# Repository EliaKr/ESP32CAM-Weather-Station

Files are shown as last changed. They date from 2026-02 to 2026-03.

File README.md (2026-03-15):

# ESP32CAM-Weather-Station

## Electronics

This project uses a custom weather-station PCB that combines **power management**, **protection**, and an **I2C sensor/expansion bus**.

### Power features
- Supports **battery input** with input protection.
- Supports **solar input** with surge/transient protection.
- Includes **battery charging** (status indicators and a battery temperature/thermistor input).
- Provides regulated rails for the rest of the system (including a **3.3V rail** for sensors/logic).
- Breakouts/headers for accessing power rails (battery and regulated output) for debugging or external loads.

### Measurement & sensing features
- On-board sensing for **battery voltage** and **solar/charging voltage**.
- On-board environmental sensing (temperature/humidity/pressure/gas resistance).
- On-board gas sensing (VOC/NOx measurements).
- On-board ambient light sensing (lux).
- ESP32-CAM on-board sky camera.

### I2C bus + expansion features
- I2C bus includes **pullups** and **ESD/transient protection**.
- Multiple **external I2C expansion headers** (3.3V / GND / SDA / SCL) for additional sensors.

### Extras
- A PCB that makes the board compatible with the Raspberry Pi Pico (Original or W or 2 or 2W) is also included in the design files.

### Media (photos and design files)

> Photos below are from **testing / bring-up** and may show temporary wiring or rework.

**PCB front (testing photo)**  
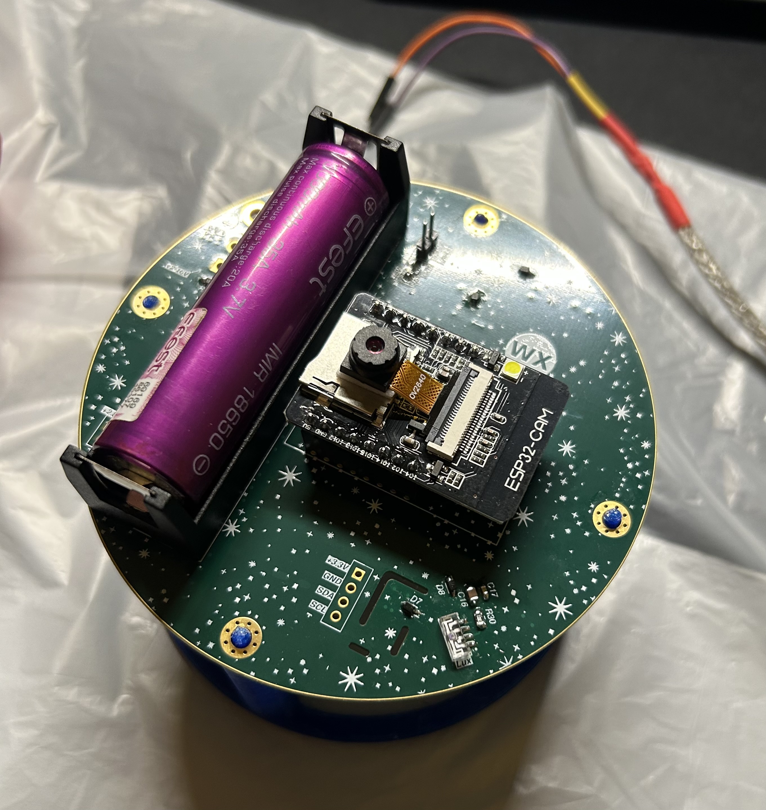
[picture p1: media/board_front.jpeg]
PCB front during testing


**PCB back (testing photo)**  
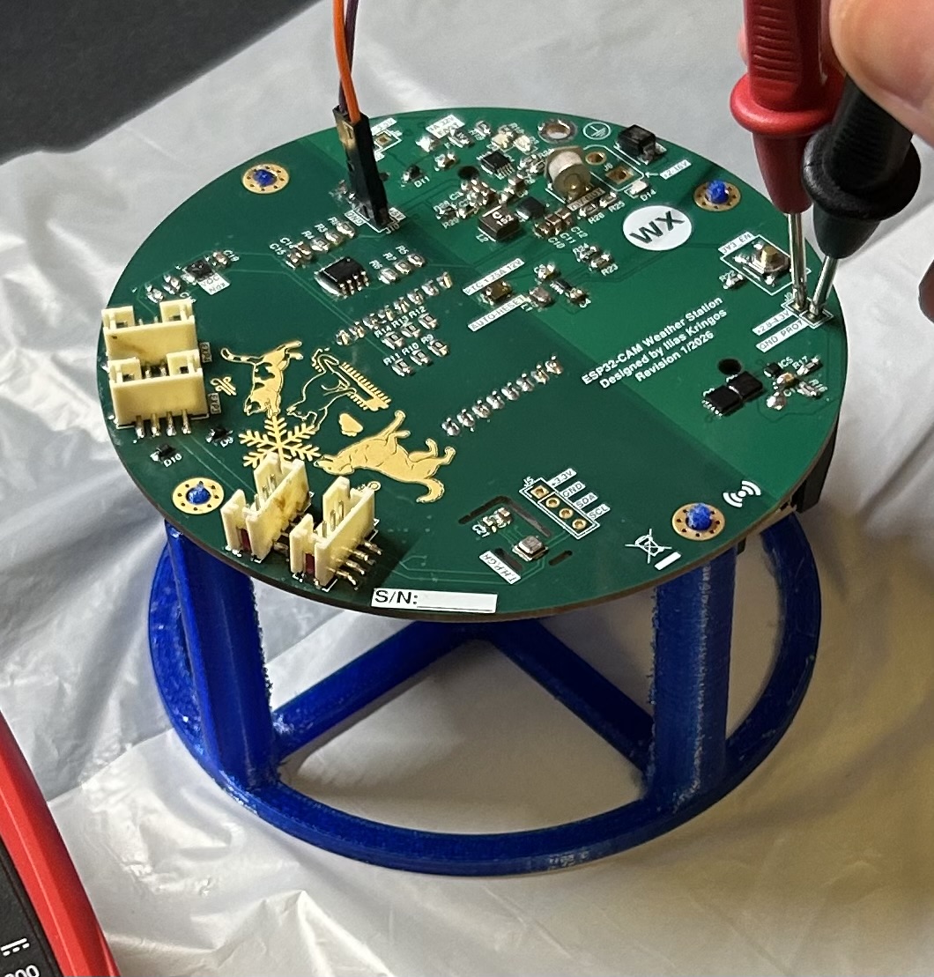
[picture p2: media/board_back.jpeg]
PCB back during testing


**KiCad PCB layout (screenshot)**  
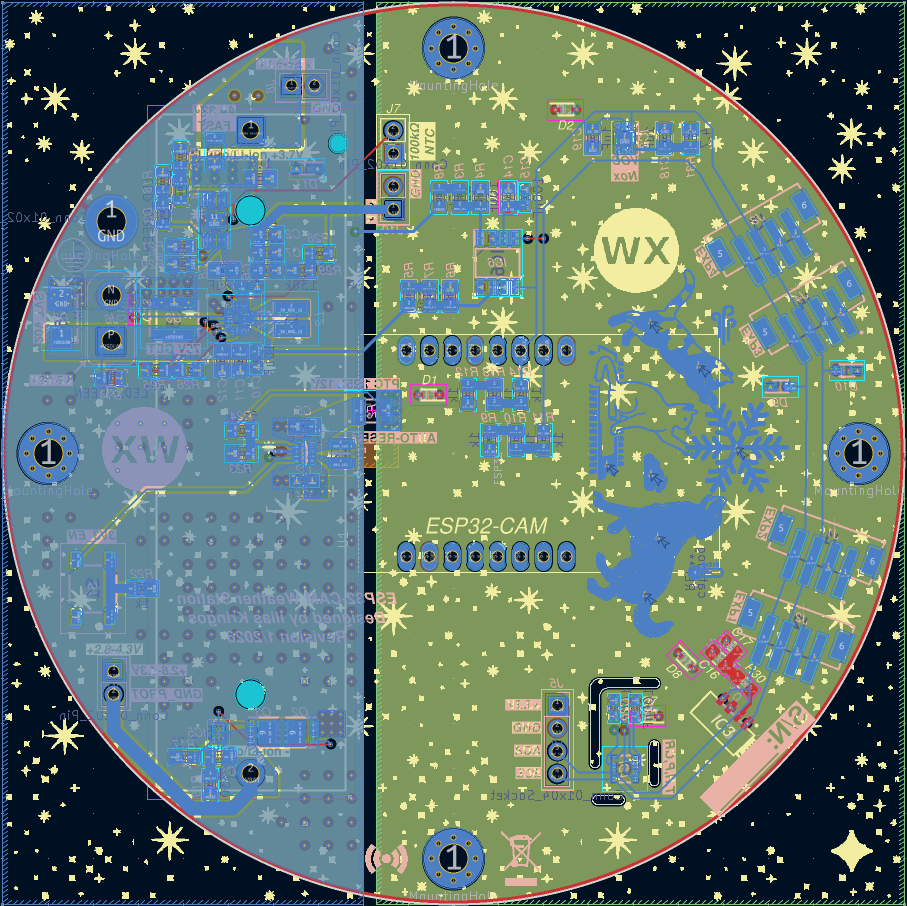
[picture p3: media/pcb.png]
KiCad PCB layout


**Schematic (export image)**  
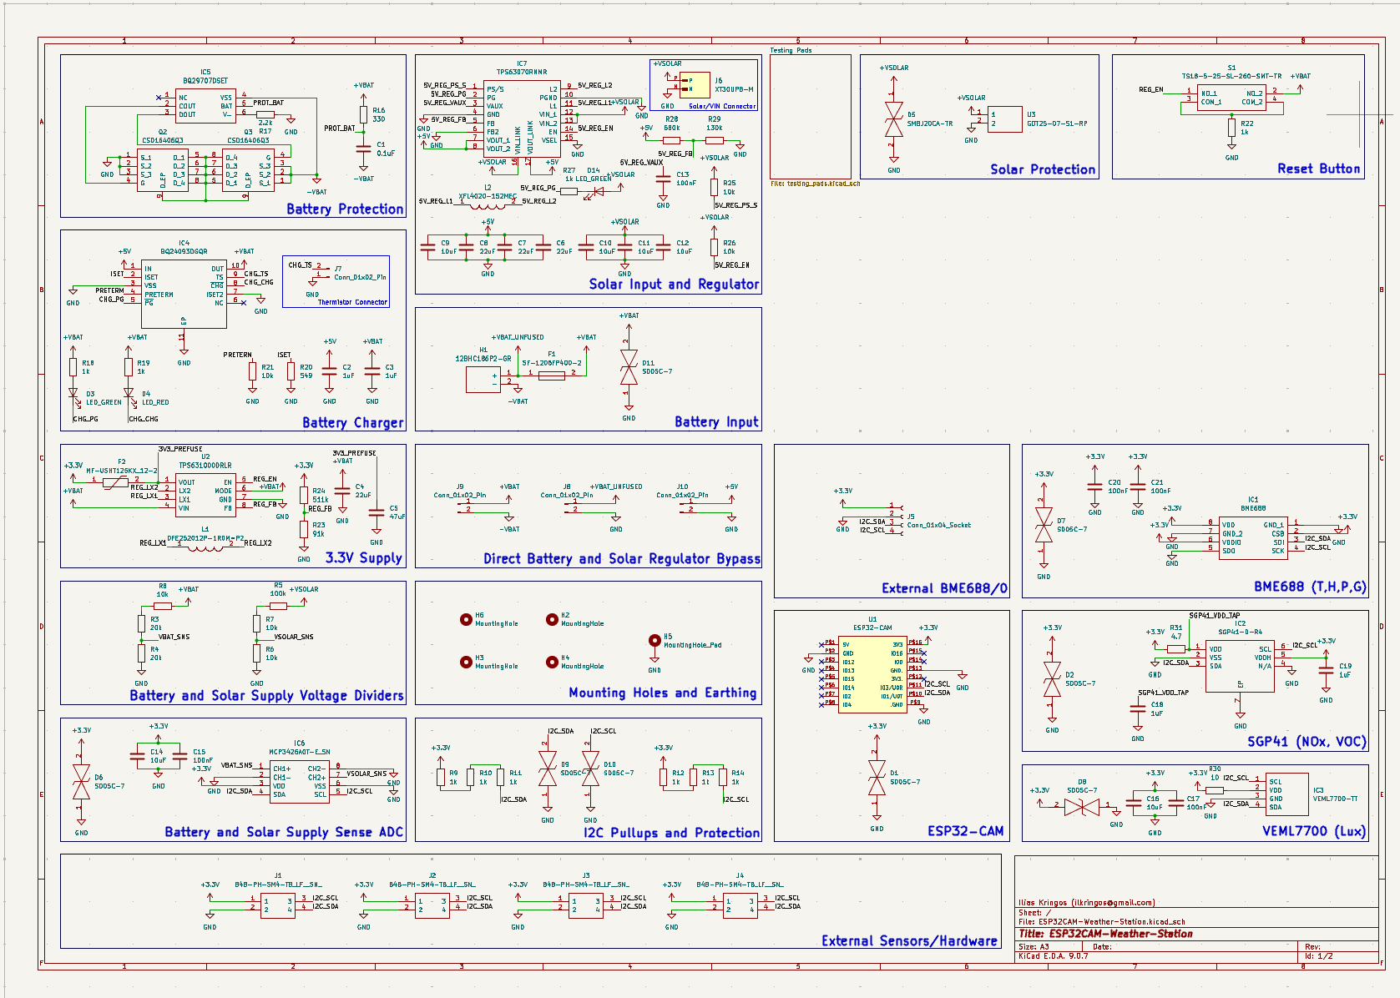
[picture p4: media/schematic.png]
Schematic


---

## Mechanical design (placeholder)

- TODO: enclosure details, mounting, weatherproofing, cable glands, venting strategy, sensor placement.
- TODO: 3D print files / CAD links, tolerances, and assembly steps.
- TODO: photos/diagrams.

---

## Software: Pico Weather Station (Client) + Local Ingest Server (HTTP + HMAC)

This project consists of:

- **Client (Raspberry Pi Pico 2 W)**: reads sensors over I2C and periodically posts measurements to a server.
- **Server (Python)**: accepts measurements over **HTTP** and protects the endpoint with:
  - Bearer token allow-list (multiple devices supported)
  - HMAC-SHA256 request signature (fast reject of unauthenticated spam)
  - Rate limiting (per IP and per token)
  - Max body size and max concurrency
  - CSV logging to two files (same schema)

> Security note: This design does **not** encrypt the data in transit (it is HTTP). It **does** prevent unauthorized clients from successfully sending data (and helps prevent trivial overload). If you need confidentiality, use HTTPS.

### Repository layout (recommended)

#### PlatformIO (client)
- `src/measurement_post_requests.cpp` (or `src/main.cpp`) — client code
- `include/client_config.h` — user-created (not committed)
- `include/wificredentials.h` — user-created (not committed)

#### Server (Python)
- `server/server_config.py`
- `server/server_http_hmac.py`

---

### 1) Server setup (Python)

#### 1.1 Requirements
- Python 3.9+ recommended (stdlib only)

No pip packages required.

#### 1.2 Files
Create a directory (example):
```
server/
  server_http_hmac.py
  server_config.py
```

#### 1.3 Configure `server_config.py`
Key options:
- Bind / endpoint: `HOST`, `PORT`, `INGEST_PATH`
- Auth: `AUTH_TOKENS`, `ALLOW_BEARER_HEADER`
- Protections: `REQUIRE_HMAC`, `REQUIRE_TIMESTAMP`, `RATE_LIMIT_*`, `MAX_BODY_BYTES`, `MAX_CONCURRENT_REQUESTS`
- CSV: `CSV_PATH_1`, `CSV_PATH_2`, `CSV_HEADER`

> If you are not setting time on the Pico (no NTP), set `REQUIRE_TIMESTAMP = False`.

#### 1.4 Run the server
From the `server/` directory:
```bash
python3 server_http_hmac.py
```

#### 1.5 Test health endpoint
```bash
curl http://<server-ip>:<port>/health
```

---

### 2) Client setup (PlatformIO / Pico 2 W)

#### 2.1 Create user config headers (required)
Create these two files under the PlatformIO include directory:
- `include/client_config.h`
- `include/wificredentials.h`

These should not be committed (they contain secrets).

##### `include/wificredentials.h`
```cpp
#pragma once

#define WIFI_SSID "YOUR_WIFI_SSID"
#define WIFI_PASS "YOUR_WIFI_PASSWORD"

#define USE_STATIC_IP 1

#if USE_STATIC_IP
  #define WIFI_LOCAL_IP   IPAddress(192,168,2,55)
  #define WIFI_DNS_IP     IPAddress(1,1,1,1)
  #define WIFI_GATEWAY_IP IPAddress(192,168,2,1)
  #define WIFI_SUBNET_IP  IPAddress(255,255,255,0)
#endif
```

##### `include/client_config.h`
```cpp
#pragma once

#define DEVICE_ID "pico2w-01"
#define SERVER_URL "http://192.168.2.8:8080/ingest"

// Token secret: must exist in server_config.AUTH_TOKENS
#define AUTH_TOKEN "CHANGE_ME_TO_A_LONG_RANDOM_SECRET"

#define POST_INTERVAL_MS 1000
#define HTTP_TIMEOUT_MS 5000
```

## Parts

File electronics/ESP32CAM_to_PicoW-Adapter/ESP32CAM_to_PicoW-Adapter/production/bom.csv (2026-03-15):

Designator | Footprint | Quantity | Value | LCSC Part #
A1 | RaspberryPi_Pico_Common_THT | 1 | RaspberryPi_Pico_W
D1 | D_DO-41_SOD81_P10.16mm_Horizontal | 1 | 1N5818
U1 | ESP32-CAM | 1 | ESP32-CAM

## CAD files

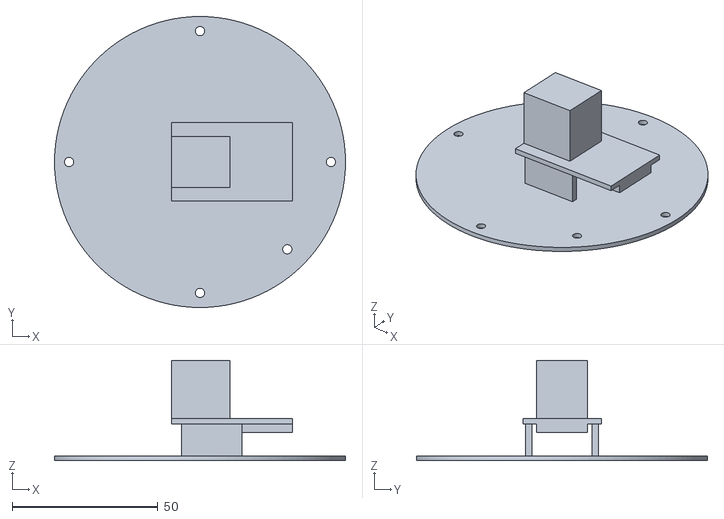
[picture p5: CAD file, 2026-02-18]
mechanical/Board.stl
100.0 x 100.0 x 34.4

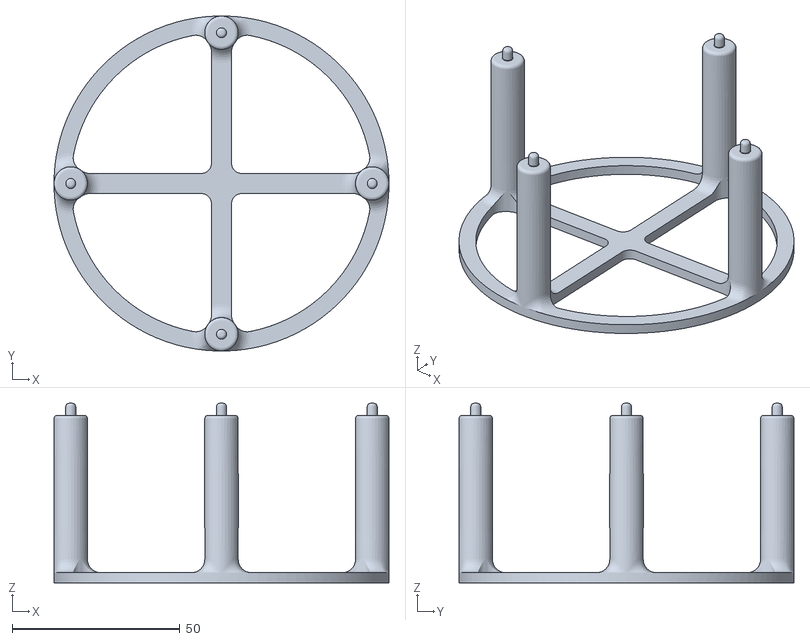
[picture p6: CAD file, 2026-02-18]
mechanical/Soldering+Base.stl
100.0 x 100.0 x 53.6

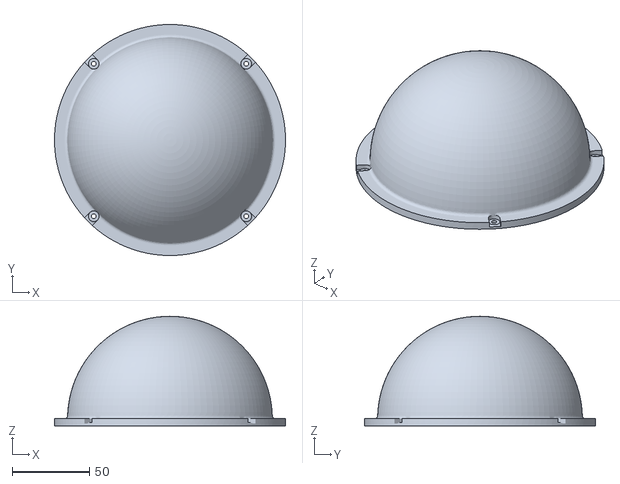
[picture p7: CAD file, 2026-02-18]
mechanical/Lid.stl
150.0 x 150.0 x 71.1

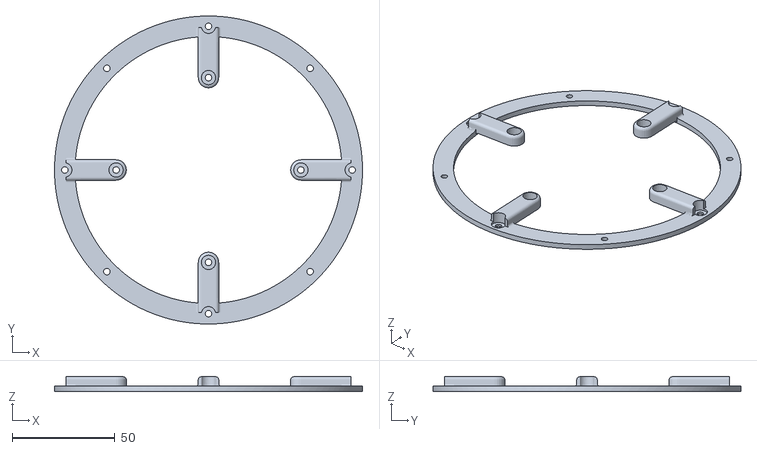
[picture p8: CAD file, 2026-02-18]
mechanical/Mount.stl
150.0 x 150.0 x 7.10

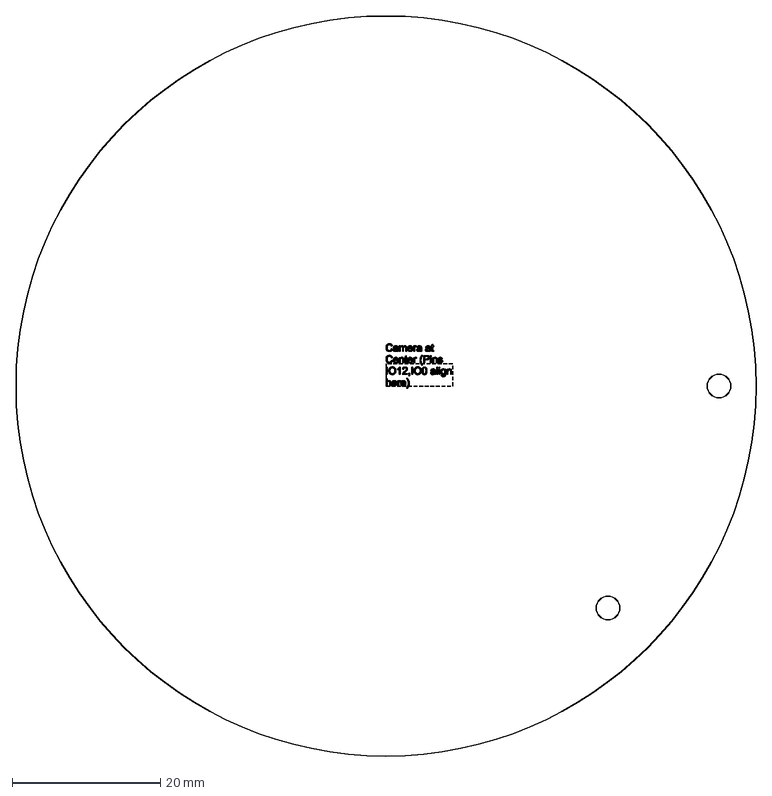
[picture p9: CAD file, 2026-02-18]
mechanical/Board Shape.dxf
100.0 x 100.0 mm

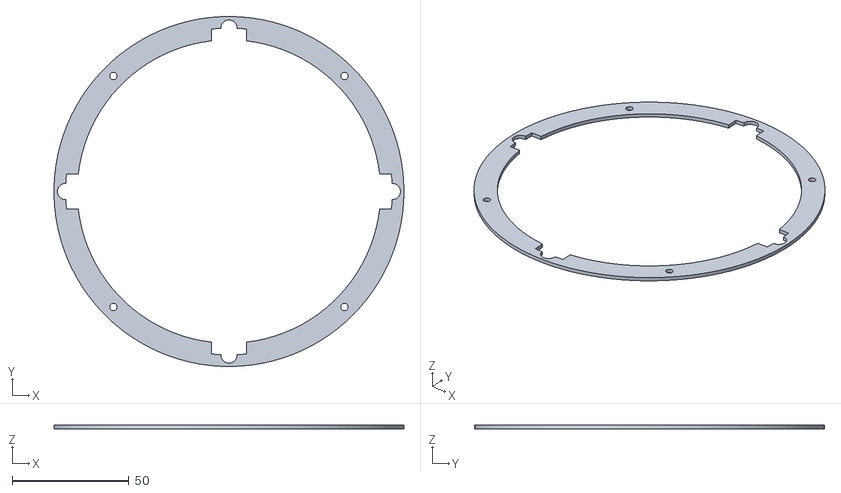
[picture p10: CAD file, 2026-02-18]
mechanical/Gasket.stl
150.0 x 150.0 x 1.60

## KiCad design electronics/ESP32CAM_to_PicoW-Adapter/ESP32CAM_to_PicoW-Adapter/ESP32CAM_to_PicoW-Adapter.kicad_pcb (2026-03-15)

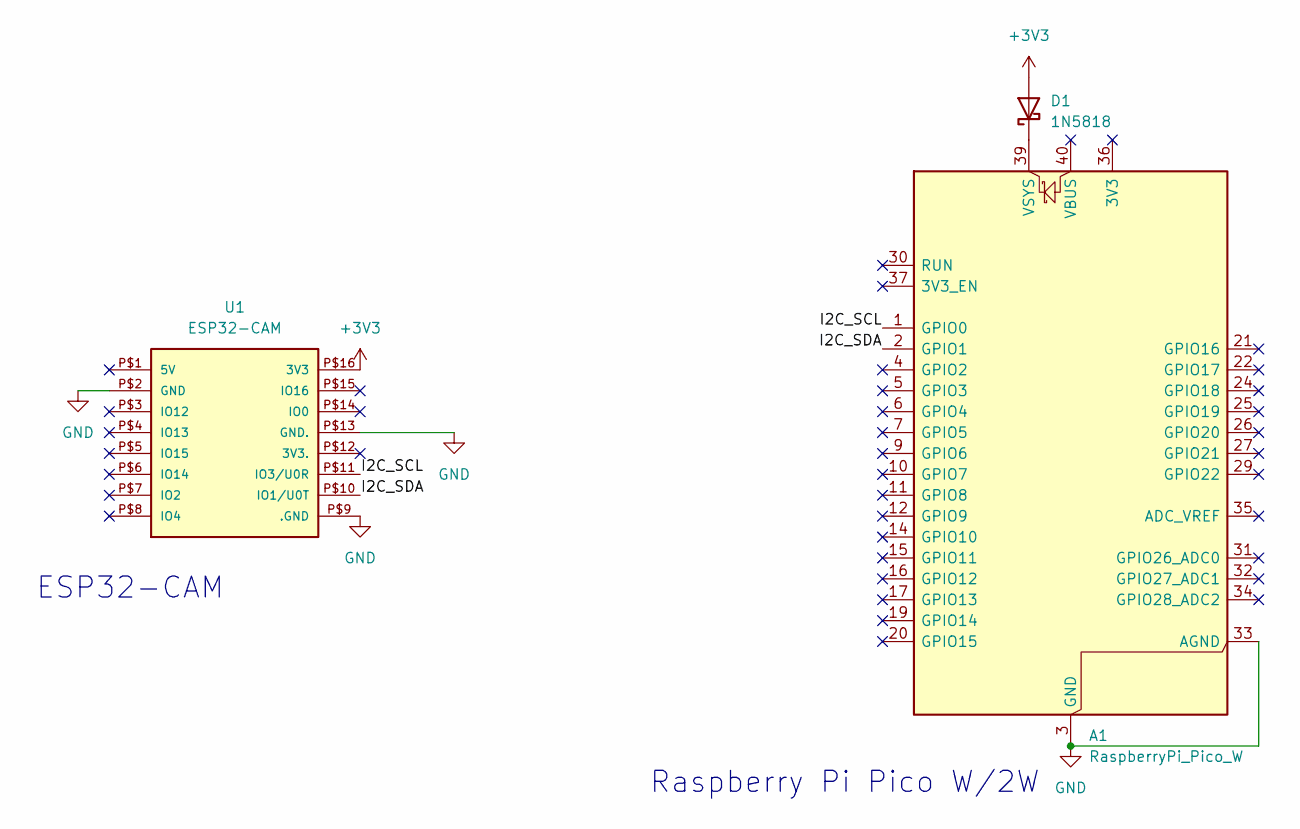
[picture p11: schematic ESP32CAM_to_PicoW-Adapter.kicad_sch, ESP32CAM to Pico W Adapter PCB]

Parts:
A1: RaspberryPi_Pico_W; RaspberryPi_Pico_Common_THT
D1: 1N5818; D_DO-41_SOD81_P10.16mm_Horizontal
U1: ESP32-CAM

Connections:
+3V3: D1.2 (A), U1.P$16 (3V3)
/I2C_SCL: A1.1 (GPIO0), U1.P$11 (IO3/U0R)
/I2C_SDA: A1.2 (GPIO1), U1.P$10 (IO1/U0T)
GND: A1.3 (GND), A1.8 (GND), A1.13 (GND), A1.18 (GND), A1.23 (GND), A1.28 (GND), A1.33 (AGND), A1.38 (GND), U1.P$2 (GND), U1.P$9 (.GND), U1.P$13 (GND.)
unnamed: A1.39 (VSYS), D1.1 (K)

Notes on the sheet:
ESP32-CAM
Raspberry Pi Pico W/2W

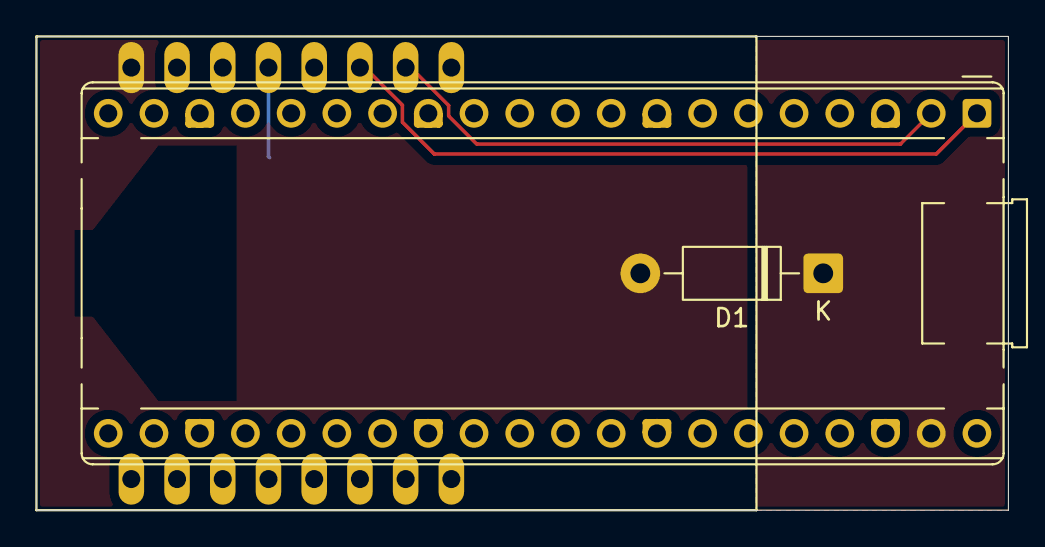
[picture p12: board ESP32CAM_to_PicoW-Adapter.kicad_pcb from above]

Board: 2 copper layers, 54.0 x 26.3 mm, 3 parts (0 on the bottom side), 5 nets.

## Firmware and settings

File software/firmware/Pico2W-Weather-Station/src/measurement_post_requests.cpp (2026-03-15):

#define MEASUREMENT_POST_REQUESTS
#ifdef MEASUREMENT_POST_REQUESTS

// ===================== User options =====================
// Measurement cadence (time between posts)
#define MEASUREMENT_INTERVAL_MS 10000

// Low power between measurements:
// 0 = keep WiFi on, simple delay
// 1 = turn WiFi off between measurements (saves a lot of power)
#define USE_LOW_POWER_BETWEEN_MEASUREMENTS 1
// ========================================================

#include <Arduino.h>
#include <Wire.h>

#include <Adafruit_BME680.h>
#include <MCP342x.h>
#include <Adafruit_VEML7700.h>
#include <Adafruit_SGP41.h>
#include <VOCGasIndexAlgorithm.h>
#include <NOxGasIndexAlgorithm.h>

#include <WiFi.h>
#include <HTTPClient.h>

#include "wificredentials.h"
#include "client_config.h"

// -------------------- Sensors --------------------
static const uint8_t BME_ADDR = 0x76;
Adafruit_BME680 bme;

static const uint8_t MCP3426_ADDR = 0x68;
MCP342x adc(MCP3426_ADDR);

static const MCP342x::Resolution ADC_RES = MCP342x::resolution16;
static const MCP342x::Gain       ADC_GAIN = MCP342x::gain1;

// Divider ratios: V_in = V_adc * (Rtop + Rbottom) / Rbottom
static const float VBAT_RTOP_OHMS   = 30000.0f;
static const float VBAT_RBOT_OHMS   = 20000.0f;
static const float VSOLAR_RTOP_OHMS = 110000.0f;
static const float VSOLAR_RBOT_OHMS = 10000.0f;

static const float VBAT_DIVIDER   = (VBAT_RTOP_OHMS + VBAT_RBOT_OHMS) / VBAT_RBOT_OHMS;       // 2.5
static const float VSOLAR_DIVIDER = (VSOLAR_RTOP_OHMS + VSOLAR_RBOT_OHMS) / VSOLAR_RBOT_OHMS; // 12.0

Adafruit_VEML7700 veml;

Adafruit_SGP41 sgp;
VOCGasIndexAlgorithm vocAlgorithm;
NOxGasIndexAlgorithm noxAlgorithm;

// Track which sensors are present; missing ones should not block loop()
static bool g_bme_ok  = false;
static bool g_mcp_ok  = false;
static bool g_veml_ok = false;
static bool g_sgp_ok  = false;

// -------------------- Sample --------------------
struct Sample {
  uint32_t ms = 0;

  float tempC = NAN;
  float humPct = NAN;
  float pressHpa = NAN;
  uint32_t gasOhms = 0;
  float altM = NAN;

  float vbatV = NAN;
  float vsolarV = NAN;

  float alsLux = NAN;
  uint16_t white = 0;

  uint16_t srawVoc = 0;
  uint16_t srawNox = 0;
  int32_t vocIndex = -1;
  int32_t noxIndex = -1;
  bool sgpOk = false;
};

static uint32_t g_lastPostMs = 0;

// -------------------- MCP helpers --------------------
static float mcpVoltsPerCode(const MCP342x::Resolution &res, const MCP342x::Gain &gain) {
  const int r = (int)res;
  const int g = (int)gain;
  const float fs = 2.048f / (float)g;
  const float counts = (float)(1UL << (r - 1));
  return fs / counts;
}

static float mcpCodeToInputVolts(long code, const MCP342x::Resolution &res, const MCP342x::Gain &gain) {
  return (float)code * mcpVoltsPerCode(res, gain);
}

static bool readMcpRaw(MCP342x::Channel ch, long &valueOut) {
  MCP342x::Config status;
  const uint8_t err = adc.convertAndRead(ch, MCP342x::oneShot, ADC_RES, ADC_GAIN, 1000000, valueOut, status);
  return err == 0;
}

// -------------------- HMAC-SHA256 (BearSSL; works on rpipico2w / Arduino-Pico) --------------------
#include <bearssl/bearssl.h>

static String hmacSha256Hex(const char *key, const uint8_t *msg, size_t msgLen) {
  unsigned char mac[br_sha256_SIZE];

  br_hmac_key_context kc;
  br_hmac_context ctx;

  br_hmac_key_init(&kc, &br_sha256_vtable, key, strlen(key));
  br_hmac_init(&ctx, &kc, 0);
  br_hmac_update(&ctx, msg, msgLen);
  br_hmac_out(&ctx, mac);

  static const char *hex = "0123456789abcdef";
  String s;
  s.reserve(64);
  for (size_t i = 0; i < sizeof(mac); i++) {
    s += hex[(mac[i] >> 4) & 0xF];
    s += hex[mac[i] & 0xF];
  }
  return s;
}

// -------------------- WiFi (use your original/known-working static-IP arg order) --------------------
static void wifiConnect() {
  WiFi.mode(WIFI_STA);
  WiFi.disconnect(true);
  delay(250);

#if USE_STATIC_IP
  // IMPORTANT: this is the SAME order as your "works on wifi" code
  WiFi.config(WIFI_LOCAL_IP, WIFI_DNS_IP, WIFI_GATEWAY_IP, WIFI_SUBNET_IP);
  Serial.print(F("# wifi_static_ip "));
  Serial.println(WIFI_LOCAL_IP);
#endif

  WiFi.begin(WIFI_SSID, WIFI_PASS);

  Serial.print(F("# wifi_connecting ssid="));
  Serial.println(WIFI_SSID);

  const uint32_t start = millis();
  while (WiFi.status() != WL_CONNECTED) {
    delay(250);
    Serial.print('.');
    if (millis() - start > 20000) break;
  }
  Serial.println();

  Serial.print(F("# wifi_status="));
  Serial.println((int)WiFi.status());

  if (WiFi.status() == WL_CONNECTED) {
    Serial.print(F("# wifi_ok ip=")); Serial.println(WiFi.localIP());
    Serial.print(F("# rssi="));       Serial.println(WiFi.RSSI());
  } else {
    Serial.println(F("# wifi_failed"));
  }
}

static void wifiOff() {
#if USE_LOW_POWER_BETWEEN_MEASUREMENTS
  WiFi.disconnect(true);
  delay(50);
  WiFi.mode(WIFI_OFF);
  delay(50);
#endif
}

// -------------------- Sensor power behaviors --------------------
static void vemlShutdown(bool enable) {
  if (!g_veml_ok) return;
  // Adafruit_VEML7700 provides enable/disable via power-save/shutdown in most versions.
  // `enable(false)` puts it into shutdown (very low current).
  veml.enable(!enable ? true : false); // placeholder safety if library differs
}

// More robust: use the API that exists in Adafruit_VEML7700 v2.x
static void vemlSetEnabled(bool on) {
  if (!g_veml_ok) return;
  // In Adafruit VEML7700 Library 2.1.x there is: veml.enable(bool)
  veml.enable(on);
}

// BME forced-mode only:
// Adafruit_BME680 is already forced-mode when you call performReading().
// The key is: do NOT use continuous mode loops; just call performReading() once per cycle.

static void sensorsPreSleep() {
  // Put VEML into shutdown between measurements
  vemlSetEnabled(false);
}

static void sensorsPostWake() {
  // Re-enable VEML
  vemlSetEnabled(true);
  delay(5);
}

static void waitBetweenMeasurements() {
#if USE_LOW_POWER_BETWEEN_MEASUREMENTS
  sensorsPreSleep();
  wifiOff();
#endif

  Serial.print(F("# sleep_ms="));
  Serial.println((uint32_t)MEASUREMENT_INTERVAL_MS);
  Serial.flush();

  delay(MEASUREMENT_INTERVAL_MS);

#if USE_LOW_POWER_BETWEEN_MEASUREMENTS
  // WiFi is re-enabled in loop() before reconnect
  sensorsPostWake();
#endif
}

// -------------------- Sampling --------------------
static void sgpConditioning10sNonBlocking() {
  if (!g_bme_ok || !g_sgp_ok) return;

  Serial.println(F("# sgp41 conditioning (10s)"));
  for (uint8_t i = 0; i < 10; i++) {
    uint16_t sraw_voc = 0;
    if (bme.performReading()) {
      (void)sgp.executeConditioning(&sraw_voc, bme.humidity, bme.temperature);
      (void)vocAlgorithm.process(sraw_voc);
    }
    delay(1000);
  }
  Serial.println(F("# sgp41 conditioning done"));
}

static Sample readSample() {
  Sample s;
  s.ms = millis();

  // BME forced-mode: performReading() triggers a single measurement.
  if (g_bme_ok && bme.performReading()) {
    s.tempC = bme.temperature;
    s.humPct = bme.humidity;
    s.pressHpa = bme.pressure / 100.0f;
    s.gasOhms = bme.gas_resistance;
    s.altM = bme.readAltitude(1013.25f);
  }

  // MCP one-shot conversions only when needed
  long vbatRaw = 0, vsolarRaw = 0;
  const bool ok1 = g_mcp_ok && readMcpRaw(MCP342x::channel1, vbatRaw);
  const bool ok2 = g_mcp_ok && readMcpRaw(MCP342x::channel2, vsolarRaw);

  const float vbat_adc   = ok1 ? mcpCodeToInputVolts(vbatRaw, ADC_RES, ADC_GAIN) : NAN;
  const float vsolar_adc = ok2 ? mcpCodeToInputVolts(vsolarRaw, ADC_RES, ADC_GAIN) : NAN;
  s.vbatV   = isnan(vbat_adc)   ? NAN : vbat_adc * VBAT_DIVIDER;
  s.vsolarV = isnan(vsolar_adc) ? NAN : vsolar_adc * VSOLAR_DIVIDER;

  // VEML (only read if enabled/present)
  if (g_veml_ok) {
    s.alsLux = veml.readLux();
    s.white = veml.readWhite();
  }

  // SGP (needs temp/RH)
  if (g_sgp_ok && g_bme_ok && !isnan(s.tempC) && !isnan(s.humPct)) {
    s.sgpOk = sgp.measureRawSignals(&s.srawVoc, &s.srawNox, s.humPct, s.tempC);
    if (s.sgpOk) {
      s.vocIndex = vocAlgorithm.process(s.srawVoc);
      s.noxIndex = noxAlgorithm.process(s.srawNox);
    }
  } else {
    s.sgpOk = false;
    s.srawVoc = 0;
    s.srawNox = 0;
    s.vocIndex = -1;
    s.noxIndex = -1;
  }

  return s;
}

static String buildJson(const Sample &s) {
  String body;
  body.reserve(700);
  body += "{";
  body += "\"device_id\":\"" + String(DEVICE_ID) + "\",";
  body += "\"ms\":" + String(s.ms) + ",";
  body += "\"temp_c\":" + String(s.tempC, 2) + ",";
  body += "\"hum_pct\":" + String(s.humPct, 2) + ",";
  body += "\"press_hpa\":" + String(s.pressHpa, 2) + ",";
  body += "\"gas_ohms\":" + String(s.gasOhms) + ",";
  body += "\"alt_m\":" + String(s.altM, 2) + ",";
  body += "\"vbat_v\":" + String(s.vbatV, 6) + ",";
  body += "\"vsolar_v\":" + String(s.vsolarV, 6) + ",";
  body += "\"als_lux\":" + String(s.alsLux, 2) + ",";
  body += "\"white\":" + String(s.white) + ",";
  body += "\"sgp41_sraw_voc\":" + String(s.srawVoc) + ",";
  body += "\"sgp41_sraw_nox\":" + String(s.srawNox) + ",";
  body += "\"sgp41_voc_index\":" + String(s.vocIndex) + ",";
  body += "\"sgp41_nox_index\":" + String(s.noxIndex) + ",";
  body += "\"sgp41_ok\":" + String(s.sgpOk ? "true" : "false");
  body += "}";
  return body;
}

static bool postJsonHmac(const String &jsonBody) {
  if (WiFi.status() != WL_CONNECTED) return false;

  const uint32_t ts = 0; // set REQUIRE_TIMESTAMP=False server-side unless you add NTP
  const String sig = hmacSha256Hex(AUTH_TOKEN, (const uint8_t*)jsonBody.c_str(), jsonBody.length());

  HTTPClient http;
  http.setTimeout(HTTP_TIMEOUT_MS);

  if (!http.begin(SERVER_URL)) {
    Serial.println(F("# http_begin_failed"));
    return false;
  }

  http.addHeader("Content-Type", "application/json");
  http.addHeader("Authorization", String("Bearer ") + AUTH_TOKEN);
  http.addHeader("X-Timestamp", String(ts));
  http.addHeader("X-Signature", sig);

  const int code = http.POST((uint8_t*)jsonBody.c_str(), jsonBody.length());

  Serial.print(F("# http_post code="));
  Serial.print(code);

  if (code < 0) {
    Serial.print(F(" err="));
    Serial.println(http.errorToString(code));
    http.end();
    return false;
  }

  const String resp = http.getString();
  Serial.print(F(" resp="));
  Serial.println(resp);

  http.end();
  return (code >= 200 && code < 300);
}

static void printPresence() {
  Serial.print(F("# present bme="));  Serial.print(g_bme_ok ? "1" : "0");
  Serial.print(F(" mcp="));           Serial.print(g_mcp_ok ? "1" : "0");
  Serial.print(F(" veml="));          Serial.print(g_veml_ok ? "1" : "0");
  Serial.print(F(" sgp="));           Serial.println(g_sgp_ok ? "1" : "0");
}

void setup() {
  Serial.begin(115200);
  Serial.println();
  Serial.println(F("# boot"));

  Wire.begin();

  // Detect sensors; do not block if missing
  g_bme_ok = bme.begin(BME_ADDR);
  if (!g_bme_ok) Serial.println(F("# warn: bme missing"));
  else {
    // Forced-mode only: performReading() triggers one measurement when called.
    // Just configure oversampling + heater and DON'T run any continuous loop.
    bme.setTemperatureOversampling(BME680_OS_8X);
    bme.setHumidityOversampling(BME680_OS_2X);
    bme.setPressureOversampling(BME680_OS_4X);
    bme.setIIRFilterSize(BME680_FILTER_SIZE_3);
    bme.setGasHeater(320, 150);
  }

  MCP342x::generalCallReset();
  delay(1);
  Wire.requestFrom(MCP3426_ADDR, (uint8_t)1);
  g_mcp_ok = Wire.available() > 0;
  if (!g_mcp_ok) Serial.println(F("# warn: mcp3426 missing"));

  g_veml_ok = veml.begin();
  if (!g_veml_ok) {
    Serial.println(F("# warn: veml7700 missing"));
  } else {
    veml.setIntegrationTime(VEML7700_IT_100MS);
    veml.setGain(VEML7700_GAIN_1);
    vemlSetEnabled(true);
  }

  g_sgp_ok = sgp.begin();
  if (!g_sgp_ok) Serial.println(F("# warn: sgp41 missing"));
  else {
    sgpConditioning10sNonBlocking();
  }

  printPresence();

  wifiConnect();

  Serial.print(F("# server_url="));
  Serial.println(SERVER_URL);
  Serial.print(F("# post_interval_ms="));
  Serial.println(POST_INTERVAL_MS);
}

void loop() {
#if USE_LOW_POWER_BETWEEN_MEASUREMENTS
  // If WiFi was turned off between cycles, turn it back on before reconnect.
  if (WiFi.getMode() == WIFI_OFF) {
    WiFi.mode(WIFI_STA);
    delay(50);
  }
#endif

  if (WiFi.status() != WL_CONNECTED) {
    wifiConnect();
    delay(250);
    return;
  }

  const uint32_t now = millis();
  if (now - g_lastPostMs < POST_INTERVAL_MS) {
    delay(25);
    return;
  }
  g_lastPostMs = now;

  const Sample s = readSample();
  const String body = buildJson(s);
  (void)postJsonHmac(body);

  waitBetweenMeasurements();
}

#endif

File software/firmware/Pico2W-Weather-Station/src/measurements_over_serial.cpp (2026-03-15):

//#define MEASUREMENTS_OVER_SERIAL
#ifdef MEASUREMENTS_OVER_SERIAL
#include <Arduino.h>
#include <Wire.h>
#include <Adafruit_BME680.h>
#include <MCP342x.h>
#include <Adafruit_VEML7700.h>
#include <Adafruit_SGP41.h>
#include <VOCGasIndexAlgorithm.h>
#include <NOxGasIndexAlgorithm.h>

// -------------------- BME688 (Adafruit_BME680) --------------------
static const uint8_t BME_ADDR = 0x76;
Adafruit_BME680 bme; // I2C

// -------------------- MCP3426A0T (Steve Marple MCP342x) -------------------
static const uint8_t MCP3426_ADDR = 0x68;
MCP342x adc(MCP3426_ADDR);

// Use the library's types (these are small wrapper classes, not enums)
static const MCP342x::Resolution ADC_RES = MCP342x::resolution16;
static const MCP342x::Gain       ADC_GAIN = MCP342x::gain1;

// Divider ratios: V_in = V_adc * (Rtop + Rbottom) / Rbottom
static const float VBAT_RTOP_OHMS   = 30000.0f;
static const float VBAT_RBOT_OHMS   = 20000.0f;
static const float VSOLAR_RTOP_OHMS = 110000.0f;
static const float VSOLAR_RBOT_OHMS = 10000.0f;

static const float VBAT_DIVIDER  = (VBAT_RTOP_OHMS + VBAT_RBOT_OHMS) / VBAT_RBOT_OHMS;        // 2.5
static const float VSOLAR_DIVIDER = (VSOLAR_RTOP_OHMS + VSOLAR_RBOT_OHMS) / VSOLAR_RBOT_OHMS; // 12.0

// -------------------- VEML7700 (Adafruit_VEML7700) --------------------
static const uint8_t VEML7700_ADDR = 0x10; // default
Adafruit_VEML7700 veml = Adafruit_VEML7700();

// -------------------- SGP41 (Adafruit_SGP41) + Gas Index Algorithm --------------------
static const uint8_t SGP41_ADDR = 0x59; // default
Adafruit_SGP41 sgp;
VOCGasIndexAlgorithm vocAlgorithm;
NOxGasIndexAlgorithm noxAlgorithm;

// Volts per code for MCP342x using its internal full-scale of +/-2.048V / gain.
static float mcpVoltsPerCode(const MCP342x::Resolution &res, const MCP342x::Gain &gain) {
  const int r = (int)res;   // 12, 14, 16, 18
  const int g = (int)gain;  // 1, 2, 4, 8

  const float fs = 2.048f / (float)g;            // full-scale magnitude (V)
  const float counts = (float)(1UL << (r - 1));  // positive full-scale counts
  return fs / counts;
}

static float mcpCodeToInputVolts(long code, const MCP342x::Resolution &res, const MCP342x::Gain &gain) {
  return (float)code * mcpVoltsPerCode(res, gain);
}

static bool readMcpRaw(MCP342x::Channel ch, long &valueOut) {
  MCP342x::Config status;
  const uint8_t err = adc.convertAndRead(
      ch,
      MCP342x::oneShot,
      ADC_RES,
      ADC_GAIN,
      1000000, // timeout in microseconds
      valueOut,
      status);
  return err == 0;
}

static void printCsvHeader() {
  Serial.println(F("ms,temp_c,hum_pct,press_hpa,gas_ohms,alt_m,vbat_v,vsolar_v,als_lux,white,sgp41_sraw_voc,sgp41_sraw_nox,sgp41_voc_index,sgp41_nox_index"));
}

void setup() {
  Serial.begin(115200);
  while (!Serial) { delay(10); }

  Serial.println();
  Serial.println(F("# boot"));

  Wire.begin();

  MCP342x::generalCallReset();
  delay(1);

  // Probe MCP342x presence and print address
  Wire.requestFrom(MCP3426_ADDR, (uint8_t)1);
  if (!Wire.available()) {
    Serial.print(F("# error: no MCP342x device found at address 0x"));
    Serial.println(MCP3426_ADDR, HEX);
    while (true) { delay(1000); }
  }
  Serial.print(F("# mcp3426_addr=0x"));
  Serial.println(MCP3426_ADDR, HEX);

  // Init BME688 at fixed address and print it
  if (!bme.begin(BME_ADDR)) {
    Serial.print(F("# error: could not find BME688/BME680 at 0x"));
    Serial.println(BME_ADDR, HEX);
    while (true) { delay(1000); }
  }
  Serial.print(F("# bme68x_addr=0x"));
  Serial.println(BME_ADDR, HEX);

  bme.setTemperatureOversampling(BME680_OS_8X);
  bme.setHumidityOversampling(BME680_OS_2X);
  bme.setPressureOversampling(BME680_OS_4X);
  bme.setIIRFilterSize(BME680_FILTER_SIZE_3);
  bme.setGasHeater(320, 150);

  // Init VEML7700 and print address
  if (!veml.begin()) {
    Serial.print(F("# error: could not find VEML7700 at 0x"));
    Serial.println(VEML7700_ADDR, HEX);
    while (true) { delay(1000); }
  }
  Serial.print(F("# veml7700_addr=0x"));
  Serial.println(VEML7700_ADDR, HEX);

  veml.setIntegrationTime(VEML7700_IT_100MS);
  veml.setGain(VEML7700_GAIN_1);

  // Init SGP41 and print address
  if (!sgp.begin()) {
    Serial.print(F("# error: could not find SGP41 at 0x"));
    Serial.println(SGP41_ADDR, HEX);
    while (true) { delay(1000); }
  }
  Serial.print(F("# sgp41_addr=0x"));
  Serial.println(SGP41_ADDR, HEX);

  Serial.println(F("# note: voc index needs ~60s, nox index ~300s learning"));

  // Conditioning loop (10 seconds) WITH COMPENSATION using BME temp+RH.
  Serial.println(F("# sgp41 conditioning (10s, compensated with BME688)"));
  for (uint8_t i = 0; i < 10; i++) {
    uint16_t sraw_voc = 0;

    if (!bme.performReading()) {
      Serial.println(F("# error: bme.performReading() failed during conditioning"));
    } else {
      const float tC = bme.temperature;
      const float rh = bme.humidity;

      // Pass compensation: (RH %, Temp C)
      if (!sgp.executeConditioning(&sraw_voc, rh, tC)) {
        Serial.println(F("# error: sgp41 conditioning failed"));
      } else {
        // Feed voc algorithm so it can start learning immediately.
        (void)vocAlgorithm.process(sraw_voc);
      }
    }

    delay(1000);
  }
  Serial.println(F("# sgp41 conditioning done"));

  Serial.print(F("# mcp_res_bits="));
  Serial.print((int)ADC_RES);
  Serial.print(F(",mcp_gain="));
  Serial.println((int)ADC_GAIN);

  Serial.print(F("# vbat_divider="));
  Serial.println(VBAT_DIVIDER, 6);
  Serial.print(F("# vsolar_divider="));
  Serial.println(VSOLAR_DIVIDER, 6);

  printCsvHeader();
}
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

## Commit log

2026-01-11 Initial KiCad project creation commit.
    [ESP32CAM-Weather-Station.kicad_pcb, ESP32CAM-Weather-Station.kicad_sch]
2026-01-11 [WIP] Included libraries and setup board.
    [ESP32CAM-Weather-Station.kicad_pcb, ESP32CAM-Weather-Station.kicad_sch]
2026-01-11 [WIP] Placed basic parts.
    [ESP32CAM-Weather-Station.kicad_sch]
2026-01-12 [WIP] Added battery access header, I2C pullups and ADC voltage dividers.
2026-01-12 [WIP] Added ESP32-CAM, I2C Pullup, JST Connections.
    [ESP32CAM-Weather-Station.kicad_sch]
2026-01-12 [WIP] Connected GPIO pins to LEDs, Buzzer.
    [ESP32CAM-Weather-Station.kicad_sch]
2026-01-12 [WIP] Wired battery input and protection.
    [ESP32CAM-Weather-Station.kicad_sch]
2026-01-12 [WIP] Wired battery charger for 1A charge current and 500mA preterm current.
    [ESP32CAM-Weather-Station.kicad_sch, testing_pads.kicad_sch]
2026-01-12 [WIP] Wired 3v3 regulator.
    [ESP32CAM-Weather-Station.kicad_sch]
2026-01-13 [WIP] Added transient protection and mounting holes.
    [ESP32CAM-Weather-Station.kicad_sch]
2026-01-13 [WIP] Routed solar input regulator.
    [ESP32CAM-Weather-Station.kicad_sch]
2026-01-13 [WIP] Routed ADC and buzzer.
    [ESP32CAM-Weather-Station.kicad_sch]
2026-01-13 [WIP] Routed light sensor.
    [ESP32CAM-Weather-Station.kicad_sch]
2026-01-13 [WIP] Routed SGP41.
    [ESP32CAM-Weather-Station.kicad_sch]
2026-01-13 [WIP] Routed BME688.
    [ESP32CAM-Weather-Station.kicad_sch]
2026-01-13 [Ready for review] Final schematic housekeeping. Removed unusable I/O due to pin constraints (camera and SD)
    [ESP32CAM-Weather-Station.kicad_sch]
2026-01-13 [Self-review] Slight cosmetic fix.
    [ESP32CAM-Weather-Station.kicad_sch]
2026-01-15 [WIP] Added board shape.
    [ESP32CAM-Weather-Station.kicad_pcb]
2026-01-15 [WIP] Marked placement restrictions
    [ESP32CAM-Weather-Station.kicad_pcb]
2026-01-15 [WIP] Placed Basic Connectors.
    [ESP32CAM-Weather-Station.kicad_pcb]
2026-01-15 [WIP] Placed main battery protection components.
    [ESP32CAM-Weather-Station.kicad_pcb]
2026-01-15 [WIP] Placed basic 3v3 regulator parts.
    [ESP32CAM-Weather-Station.kicad_pcb, ESP32CAM-Weather-Station.kicad_sch]
2026-01-15 [WIP] Placed basic 5V regulator parts and moved 3V3 regulator so that output connects to the 3V3 plane.
    [ESP32CAM-Weather-Station.kicad_pcb, ESP32CAM-Weather-Station.kicad_sch]
2026-01-15 [WIP] Placed all power components.
    [ESP32CAM-Weather-Station.kicad_pcb]
2026-01-15 [WIP] Completed most of the placement and routing.
    [ESP32CAM-Weather-Station.kicad_pcb, ESP32CAM-Weather-Station.kicad_sch]
2026-01-16 [WIP] Power stage routed. Created board cutouts for BME688.
    [ESP32CAM-Weather-Station.kicad_pcb]
2026-01-16 [Ready for review, Passes DRC] Routing completed.
    [ESP32CAM-Weather-Station.kicad_pcb, ESP32CAM-Weather-Station.kicad_sch]
2026-01-16 [Self-review] Added via stiching on power supply side ground.
2026-01-16 [WIP] Silkscreen, designator design and placement completed.
    [ESP32CAM-Weather-Station.kicad_pcb]
2026-01-17 [WIP] Added basic functional silkscreen markings.
    [ESP32CAM-Weather-Station.kicad_pcb]
2026-01-17 [Self review] Reverted previous edit to prevent prepreg fill, grounded copper.
2026-01-19 Added mechanical files.
    [Board Shape.dxf, Board.stl, Gasket.stl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]
2026-03-14 [Final] Added ESP32CAM to PicoW adapter.
    [ESP32CAM_to_PicoW-Adapter.kicad_pcb, ESP32CAM_to_PicoW-Adapter.kicad_sch, bom.csv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]
2026-03-14 [Fix] Silkscreen fix on adapter board.
    [ESP32CAM_to_PicoW-Adapter.kicad_pcb]
2026-03-14 Added testing code for the Raspberry Pi Pico. Board verified, all components operational.
2026-03-15 Added server code and pico POST request code.
2026-03-15 Add README for ESP32CAM Weather Station project
    Added detailed project documentation for the ESP32CAM Weather Station, including electronics, software setup, and client/server configuration.
2026-03-15 Added lower power mode by disconnecting wifi between measurements.
